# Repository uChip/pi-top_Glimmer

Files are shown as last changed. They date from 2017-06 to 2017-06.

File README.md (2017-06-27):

pi-top_Glimmer  
==============

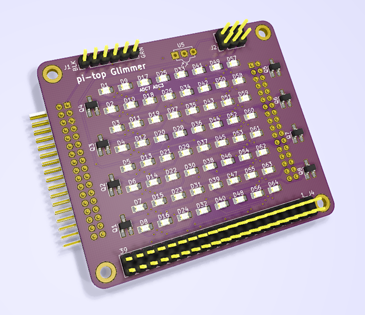
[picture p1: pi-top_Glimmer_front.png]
Accessory board for pi-top laptop or pi-topCEED
  

NOTE: This project is a work in progress and is subject to change.  See the Status section for recent changes.  

This repository contains the design files and write-up for pi-top_Glimmer.  

Note: I have no affiliation with pi-top other than being a customer.  

The pi-top Glimmer is an accessory board for the [pi-topCEED](https://pi-top.com/product/ceed).  It also fits the pi-top laptop.  The board reconstitutes the Raspberry Pi GPIO connector. Unlike the [pi-topPROTO](https://pi-top.com/buy/addon) the Glimmer places the connector optimally for connecting the ["T-Cobbler Plus - GPIO Breakout"](https://www.adafruit.com/product/2028) or the ["Pi Wedge"](https://www.sparkfun.com/products/13717).  

<picture>

The board includes support for an IR Receiver (TSOP38238 or similar) for IR remote control of the pi-top.  An on board ATmega328p (programmable Arduino style) monitors the Raw, 5V and 3.3V voltage levels of the pi-top power supply to help detect if the supply is overloaded.  

The pi-top Glimmer passes the accessory buss through to the other end of the board so that the pi-topSPEAKER or other accessories can be plugged in.  An effort has been made to use a minimum of Raspberry Pi GPIO resources so that as many HATs as possible will still work.  The pi-top HUB board commits GPIO's 7, 9,10 & 11 as the SPI buss with HUB board select on GPIO 7 (CE1_N).  To this the pi-top Glimmer adds the use of GPIOs 2 & 3 as the I2C buss (sharable with other boards) and resides at I2C address 110.  The IR Receiver is optionally connected via solder jumper to GPIO 24 (pin 18).  

Finally, the board includes an 8x8 LED (single color, on/off) array that is refreshed from the Arduino and commanded from the pi-top's Raspberry Pi.  

The software folder contains a "sketch" that is source code for the Arduino which can be changed and updated from the pi-top.  

The board is built using a combination of through-hole and (larger scale) surface mount technologies and is reasonably easy to hand assemble. I created this board for a number of reasons; to more easily enable prototyping on the pi-top, to learn more about the pi-top's accessory buss, to experiment with I2C on both RPi and Arduino, to teach myself KiCad, and to enable future projects I have in mind.  

I did it as a one off, but it seems to have some utility for classroom scenarios.  If there is interest I would be willing to make a manufacturing run of the pi-top Glimmer as a product.  

## Order PCBs  

You can order this PCB directly from OSH Park.  Click on the following link.  
  * pi-top Glimmer - https://oshpark.com/shared_projects/x6jgBiCp  

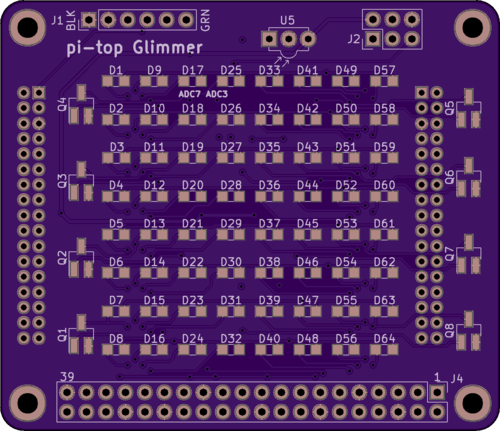
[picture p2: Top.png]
PCB Top
  

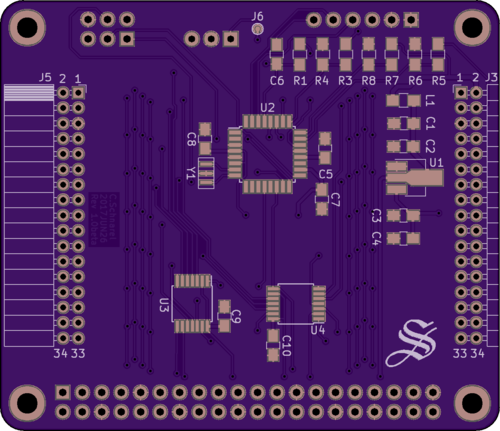
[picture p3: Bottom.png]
PCB Bottom
  

See the Bill of Materials (BOM) file in the repo Hardware folder for a parts list.  

## Status  
  * PCB (rev 1.0beta) has been checked against components and specs and is currently out for fab.  

## File Formats  

Hardware design files are in "KiCad EDA" .kicad_pcb and .sch formats (KiCAD version: (2017-05-14 revision 14bb238b3)).  A free version of the software can be downloaded from kicad-pcb.org.  

The example code is in Arduino .ino format (text).  A free version of the Arduino software can be downloaded from www.arduino.cc.  

## Distribution License  

License:  
<br /><span xmlns:dct="http://purl.org/dc/terms/" property="dct:title">pi-top Glimmer</span> by <a xmlns:cc="http://creativecommons.org/ns#" href="https://github.com/uChip/pi-top_Glimmer" property="cc:attributionName" rel="cc:attributionURL">C.Schnarel</a> is licensed under a <a rel="license" href="http://creativecommons.org/licenses/by-sa/4.0/">Creative Commons Attribution-ShareAlike 4.0 International License</a>.

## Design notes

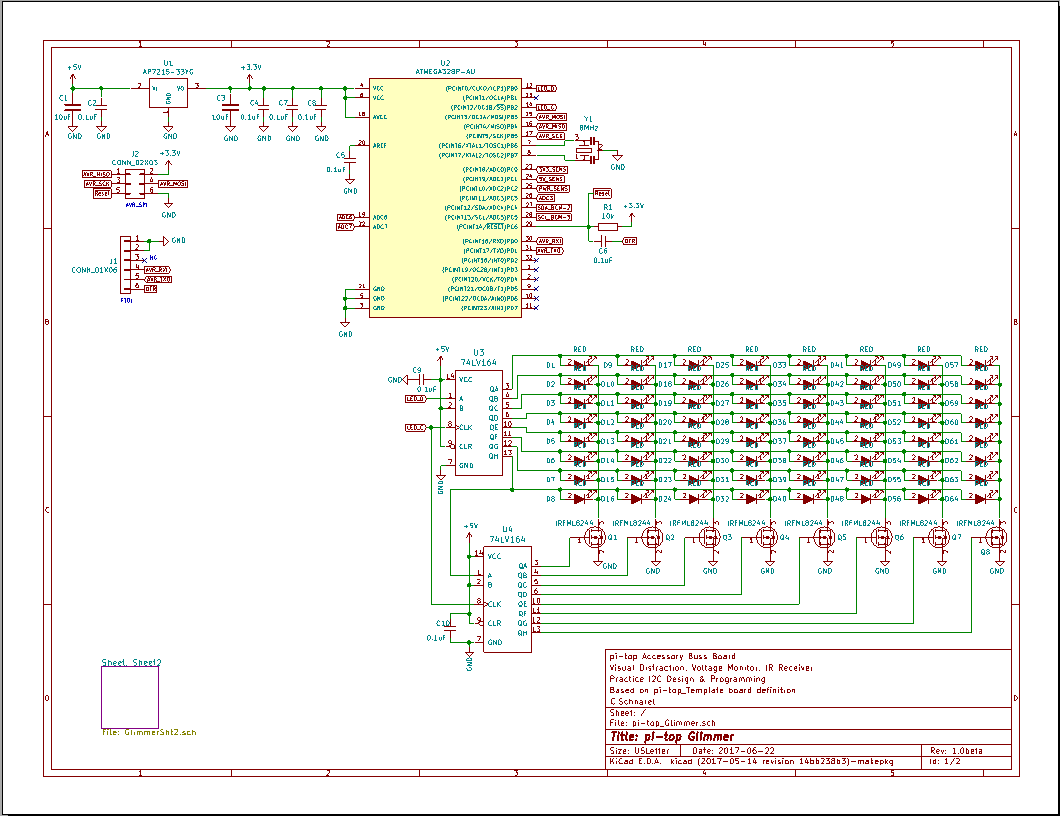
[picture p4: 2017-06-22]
schem1.PNG

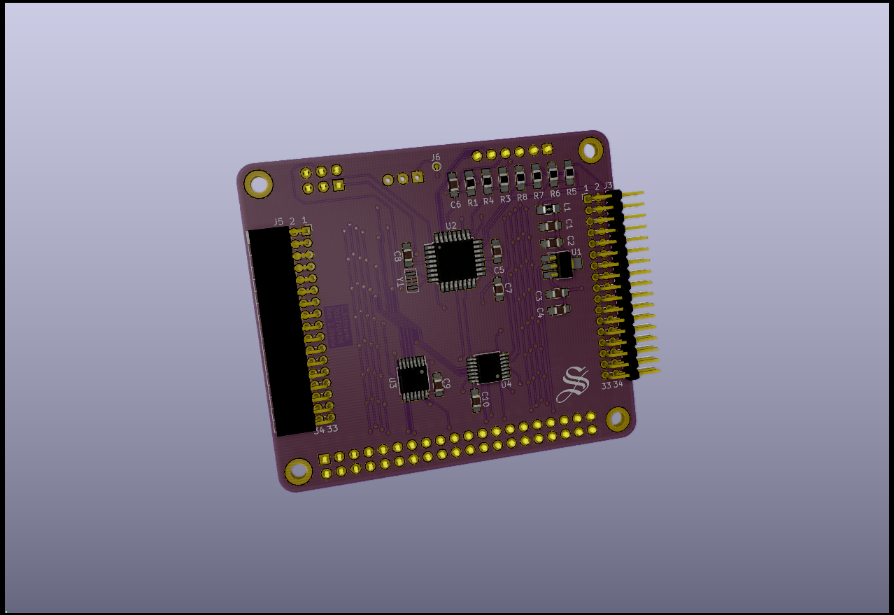
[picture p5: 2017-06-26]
pi-top_Glimmer_back.png

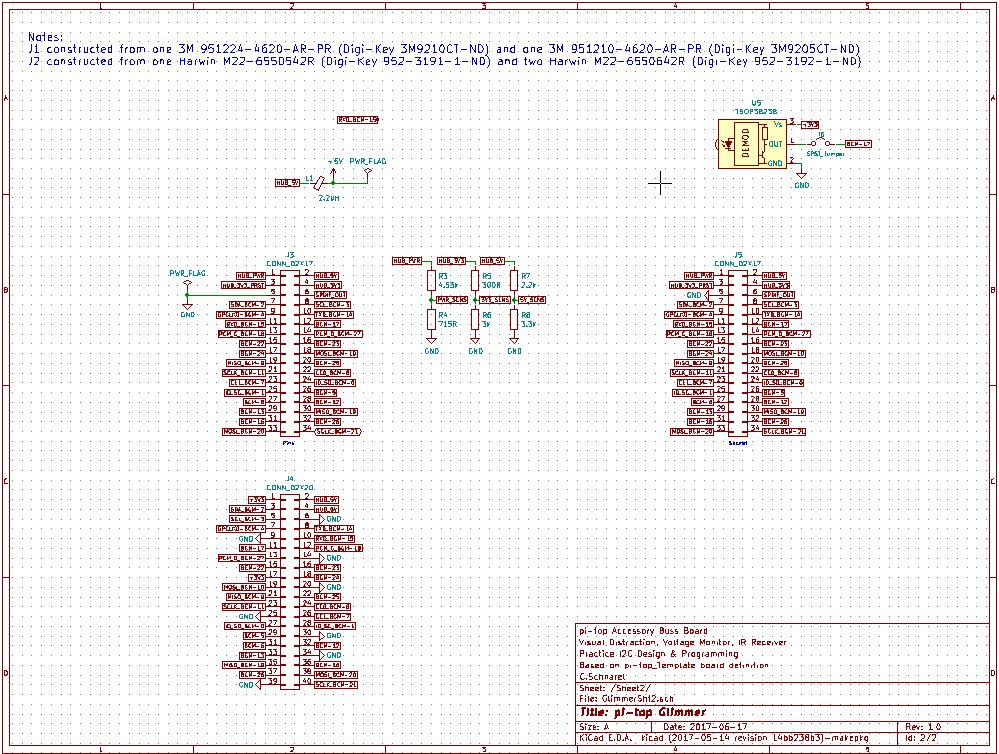
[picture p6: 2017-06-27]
schem2.PNG

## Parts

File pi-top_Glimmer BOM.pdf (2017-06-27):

## pi-top_Glimmer BOM

Id Designator | Package | Quantity Designation | Supplier and ref | $ | $ Tot
1 J5 | Socket_Strip_Angled_2x17_Pitch2.00mm | 1 | CONN_02X17 | Digi-Key #SAM11861-ND plus Digi-Key #SAM9981-ND | $ | 5.79 $ | 5.79
2 J3 | Pin_Header_Angled_2x17_Pitch2.00mm | 1 | CONN_02X17 | Digi-Key #3M9171-34-ND | $ | 4.03 $ | 4.03
3 J4 | Pin_Header_Straight_2x20_Pitch2.54mm | 1 | CONN_02X20 | Digi-Key #S2011EC-20-ND | $ | 0.93 $ | 0.93
4 U3,U4 | TSSOP-14_4.4x5mm_Pitch0.65mm | 2 | 74LV164 | Digi-Key #296-3788-1-ND | $ | 0.42 $ | 0.84
5 Q1,Q2,Q3,Q4,Q5,Q6,Q7,Q8 | SOT-23_Handsoldering | 8 | IRFML8244 | Digi-Key #IRFML8244TRPBFCT-ND | $ | 0.38 $ | 3.04

6

D18,D1,D2,D3,D4,D5,D6,D7,D8,D9,D10,D11,D12,D13,D14
,D15,D16,D17,D19,D20,D21,D22,D23,D24,D25,D26,D27,D
28,D29,D30,D31,D32,D33,D34,D35,D36,D37,D38,D39,D4
0,D41,D42,D43,D44,D45,D46,D47,D48,D49,D50,D51,D52,
D53,D54,D55,D56,D57,D58,D59,D60,D61,D62,D63,D64 | LED_0805 | 64 | RED | Digi-Key #475-1278-1-ND or similar | $ | 0.10 $ | 6.39
7 C1,C3 | C_0805_HandSoldering | 2 | 10uF | Digi-Key #C2012X5R1V106K085AC | $ | 0.73 $ | 1.46
8 C2,C4,C5,C6,C7,C8,C9,C10 | C_0805_HandSoldering | 8 | 0.1uF | Digi-Key #CC0805ZRY5V9BB104 | $ | 0.04 $ | 0.30
9 J1 | Pin_Header_Straight_1x06_Pitch2.54mm | 1 | CONN_01X06 | Digi-Key #609-3272-ND | $ | 0.34 $ | 0.34
10 L1 | L_0805_HandSoldering | 1 | FERRITE BEAD 2.5 KOHM 0805 1LN | Digi-Key #1276-6377-1-ND | $ | 0.10 $ | 0.10
11 R1 | R_0805_HandSoldering | 1 | 10k 1/8W 5% | Digi-Key #P10KACT-ND | $ | 0.10 $ | 0.10
12 R3 | R_0805_HandSoldering | 1 | 4.53k 1/8W 1% | Digi-Key #311-4.53KCRCT-ND | $ | 0.10 $ | 0.10
13 R4 | R_0805_HandSoldering | 1 | 715R 1/8W 1% | Digi-Key #311-715CRCT-ND | $ | 0.10 $ | 0.10
14 R5 | R_0805_HandSoldering | 1 | 300R 1/8W 1% | Digi-Key #311-300CRCT-ND | $ | 0.10 $ | 0.10
15 R6 | R_0805_HandSoldering | 1 | 3k 1/8W 1% | Digi-Key #311-3.00KCRCT-ND | $ | 0.10 $ | 0.10
16 R7 | R_0805_HandSoldering | 1 | 2.2k 1/8W 1% | Digi-Key #311-2.20KCRCT-ND | $ | 0.10 $ | 0.10
17 R8 | R_0805_HandSoldering | 1 | 3.3k 1/8W 1% | Digi-Key #311-3.30KCRCT-ND | $ | 0.10 $ | 0.10
18 U5 | IRReceiver_Vishay_MINICAST-3pin | 1 | TSOP38238 | Digi-Key #751-1227-ND | $ | 1.12 $ | 1.12
19 U2 | TQFP-32_7x7mm_Pitch0.8mm | 1 | ATMEGA328P-AU | Digi-Key #ATMEGA328P-AU-ND | $ | 2.07 $ | 2.07
20 Y1 | Resonator_SMD_muRata_CSTCE_3.2mm_1.3mm 1 | 8MHz | Digi-Key #490-1195-1-ND | $ | 0.48 $ | 0.48
21 U1 | SOT-89-3_Handsoldering | 1 | AP7215-33YG | Digi-Key #AP7215-33YG-13DICT-ND | $ | 0.50 $ | 0.50
$ 28.09

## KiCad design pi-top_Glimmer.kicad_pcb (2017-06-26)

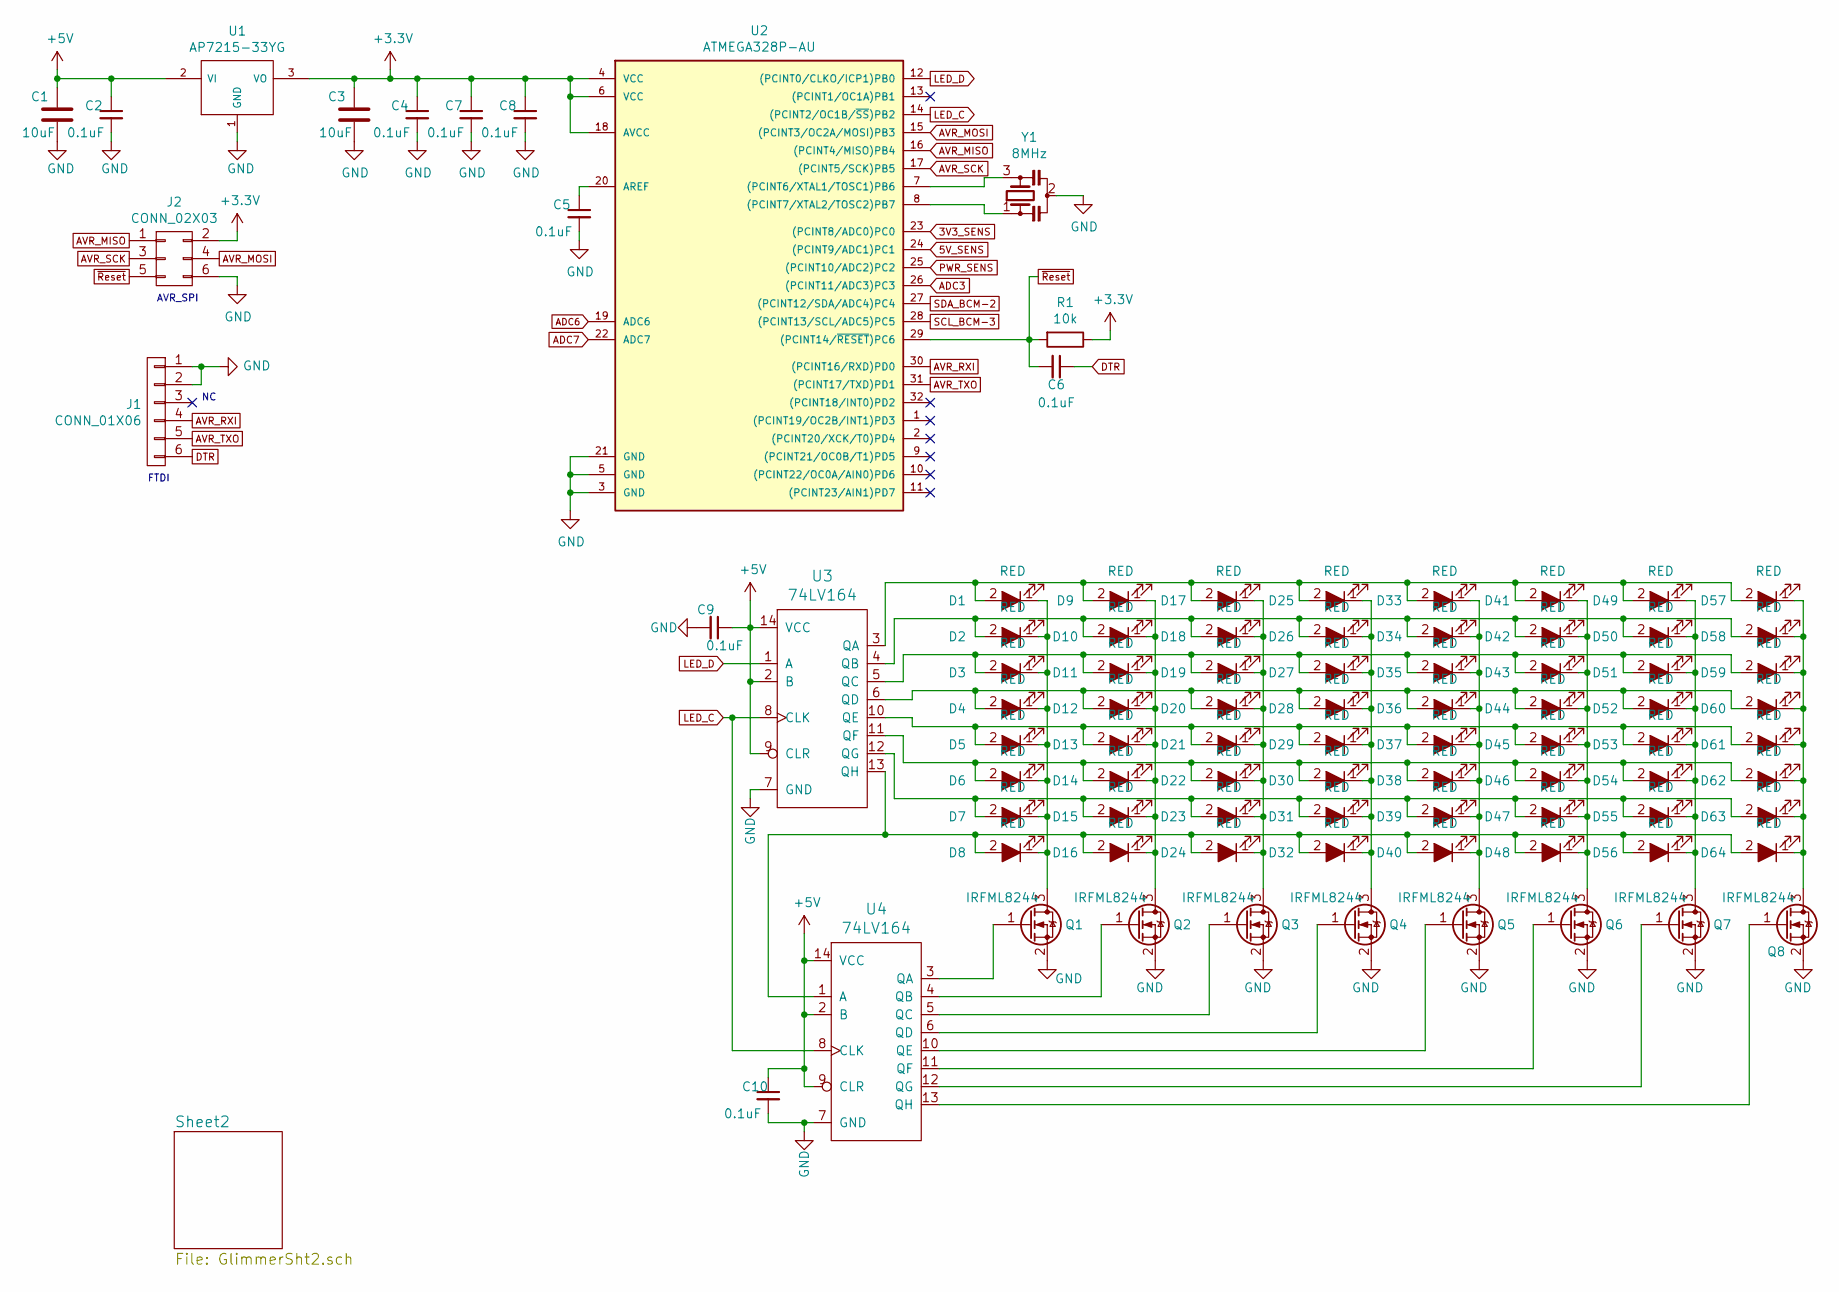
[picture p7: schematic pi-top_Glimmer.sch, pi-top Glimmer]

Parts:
C1, C3: 10uF; C_0805_HandSoldering
C2, C4, C5, C6, C7, C8, C9, C10: 0.1uF; C_0805_HandSoldering
D1, D2, D3, D4, D5, D6, D7, D8, D9, D10, D11, D12, D13, D14, D15, D16, D17, D18, D19, D20, D21, D22, D23, D24, D25, D26, D27, D28, D29, D30, D31, D32, D33, D34, D35, D36, D37, D38, D39, D40, D41, D42, D43, D44, D45, D46, D47, D48, D49, D50, D51, D52, D53, D54, D55, D56, D57, D58, D59, D60, D61, D62, D63, D64: RED; LED_0805
J1: CONN_01X06; Pin_Header_Straight_1x06_Pitch2.54mm
J2: CONN_02X03; Pin_Header_Straight_2x03_Pitch2.54mm
Q1, Q2, Q3, Q4, Q5, Q6, Q7, Q8: IRFML8244; SOT-23_Handsoldering
R1: 10k; R_0805_HandSoldering
U1: AP7215-33YG; SOT-89-3_Handsoldering
U2: ATMEGA328P-AU; TQFP-32_7x7mm_Pitch0.8mm
U3, U4: 74LV164; TSSOP-14_4.4x5mm_Pitch0.65mm
Y1: 8MHz; Resonator_SMD_muRata_CSTCE_3.2mm_1.3mm

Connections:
3V3_SENS: U2.23 ((PCINT8/ADC0)PC0); also elsewhere on the board
5V_SENS: U2.24 ((PCINT9/ADC1)PC1); also elsewhere on the board
+5V: C1.1, C2.1, C9.1, C10.1, U1.2 (VI), U3.2 (B), U3.9 (CLR), U3.14 (VCC), U4.2 (B), U4.9 (CLR), U4.14 (VCC); also elsewhere on the board
ADC3: U2.26 ((PCINT11/ADC3)PC3)
ADC6: U2.19 (ADC6)
ADC7: U2.22 (ADC7)
AVR_MISO: J2.1, U2.16 ((PCINT4/MISO)PB4)
AVR_MOSI: J2.4, U2.15 ((PCINT3/OC2A/MOSI)PB3)
AVR_RXI: J1.4, U2.30 ((PCINT16/RXD)PD0)
AVR_SCK: J2.3, U2.17 ((PCINT5/SCK)PB5)
AVR_TXO: J1.5, U2.31 ((PCINT17/TXD)PD1)
DTR: C6.1, J1.6
GND: C1.2, C2.2, C3.2, C4.2, C5.2, C7.2, C8.2, C9.2, C10.2, J1.1, J1.2, J2.6, Q1.2 (S), Q2.2 (S), Q3.2 (S), Q4.2 (S), Q5.2 (S), Q6.2 (S), Q7.2 (S), Q8.2 (S), U1.1 (GND), U2.3 (GND), U2.5 (GND), U2.21 (GND), U3.7 (GND), U4.7 (GND), Y1.2; also elsewhere on the board
LED_C: U2.14 ((PCINT2/OC1B/~SS~)PB2), U3.8 (CLK), U4.8 (CLK)
LED_D: U2.12 ((PCINT0/CLKO/ICP1)PB0), U3.1 (A)
unnamed: C5.1, U2.20 (AREF)
unnamed: D1.1 (K), D2.1 (K), D3.1 (K), D4.1 (K), D5.1 (K), D6.1 (K), D7.1 (K), D8.1 (K), Q1.3 (D)
unnamed: D1.2 (A), D9.2 (A), D17.2 (A), D25.2 (A), D33.2 (A), D41.2 (A), D49.2 (A), D57.2 (A), U3.3 (QA)
unnamed: D9.1 (K), D10.1 (K), D11.1 (K), D12.1 (K), D13.1 (K), D14.1 (K), D15.1 (K), D16.1 (K), Q2.3 (D)
unnamed: D2.2 (A), D10.2 (A), D18.2 (A), D26.2 (A), D34.2 (A), D42.2 (A), D50.2 (A), D58.2 (A), U3.4 (QB)
unnamed: D3.2 (A), D11.2 (A), D19.2 (A), D27.2 (A), D35.2 (A), D43.2 (A), D51.2 (A), D59.2 (A), U3.5 (QC)
unnamed: D4.2 (A), D12.2 (A), D20.2 (A), D28.2 (A), D36.2 (A), D44.2 (A), D52.2 (A), D60.2 (A), U3.6 (QD)
unnamed: D5.2 (A), D13.2 (A), D21.2 (A), D29.2 (A), D37.2 (A), D45.2 (A), D53.2 (A), D61.2 (A), U3.10 (QE)
unnamed: D6.2 (A), D14.2 (A), D22.2 (A), D30.2 (A), D38.2 (A), D46.2 (A), D54.2 (A), D62.2 (A), U3.11 (QF)
unnamed: D7.2 (A), D15.2 (A), D23.2 (A), D31.2 (A), D39.2 (A), D47.2 (A), D55.2 (A), D63.2 (A), U3.12 (QG)
unnamed: D8.2 (A), D16.2 (A), D24.2 (A), D32.2 (A), D40.2 (A), D48.2 (A), D56.2 (A), D64.2 (A), U3.13 (QH), U4.1 (A)
unnamed: D17.1 (K), D18.1 (K), D19.1 (K), D20.1 (K), D21.1 (K), D22.1 (K), D23.1 (K), D24.1 (K), Q3.3 (D)
unnamed: D25.1 (K), D26.1 (K), D27.1 (K), D28.1 (K), D29.1 (K), D30.1 (K), D31.1 (K), D32.1 (K), Q4.3 (D)
unnamed: D33.1 (K), D34.1 (K), D35.1 (K), D36.1 (K), D37.1 (K), D38.1 (K), D39.1 (K), D40.1 (K), Q5.3 (D)
unnamed: D41.1 (K), D42.1 (K), D43.1 (K), D44.1 (K), D45.1 (K), D46.1 (K), D47.1 (K), D48.1 (K), Q6.3 (D)
unnamed: D49.1 (K), D50.1 (K), D51.1 (K), D52.1 (K), D53.1 (K), D54.1 (K), D55.1 (K), D56.1 (K), Q7.3 (D)
unnamed: D57.1 (K), D58.1 (K), D59.1 (K), D60.1 (K), D61.1 (K), D62.1 (K), D63.1 (K), D64.1 (K), Q8.3 (D)
unnamed: Q1.1 (G), U4.3 (QA)
unnamed: Q2.1 (G), U4.4 (QB)
unnamed: Q3.1 (G), U4.5 (QC)
unnamed: Q4.1 (G), U4.6 (QD)
unnamed: Q5.1 (G), U4.10 (QE)
unnamed: Q6.1 (G), U4.11 (QF)
unnamed: Q7.1 (G), U4.12 (QG)
unnamed: Q8.1 (G), U4.13 (QH)
unnamed: U2.7 ((PCINT6/XTAL1/TOSC1)PB6), Y1.3
unnamed: U2.8 ((PCINT7/XTAL2/TOSC2)PB7), Y1.1
PWR_SENS: U2.25 ((PCINT10/ADC2)PC2); also elsewhere on the board
SCL_BCM-3: U2.28 ((PCINT13/SCL/ADC5)PC5); also elsewhere on the board
SDA_BCM-2: U2.27 ((PCINT12/SDA/ADC4)PC4); also elsewhere on the board
~Reset: C6.2, J2.5, R1.2, U2.29 ((PCINT14/~RESET~)PC6)

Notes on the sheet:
FTDI
AVR_SPI

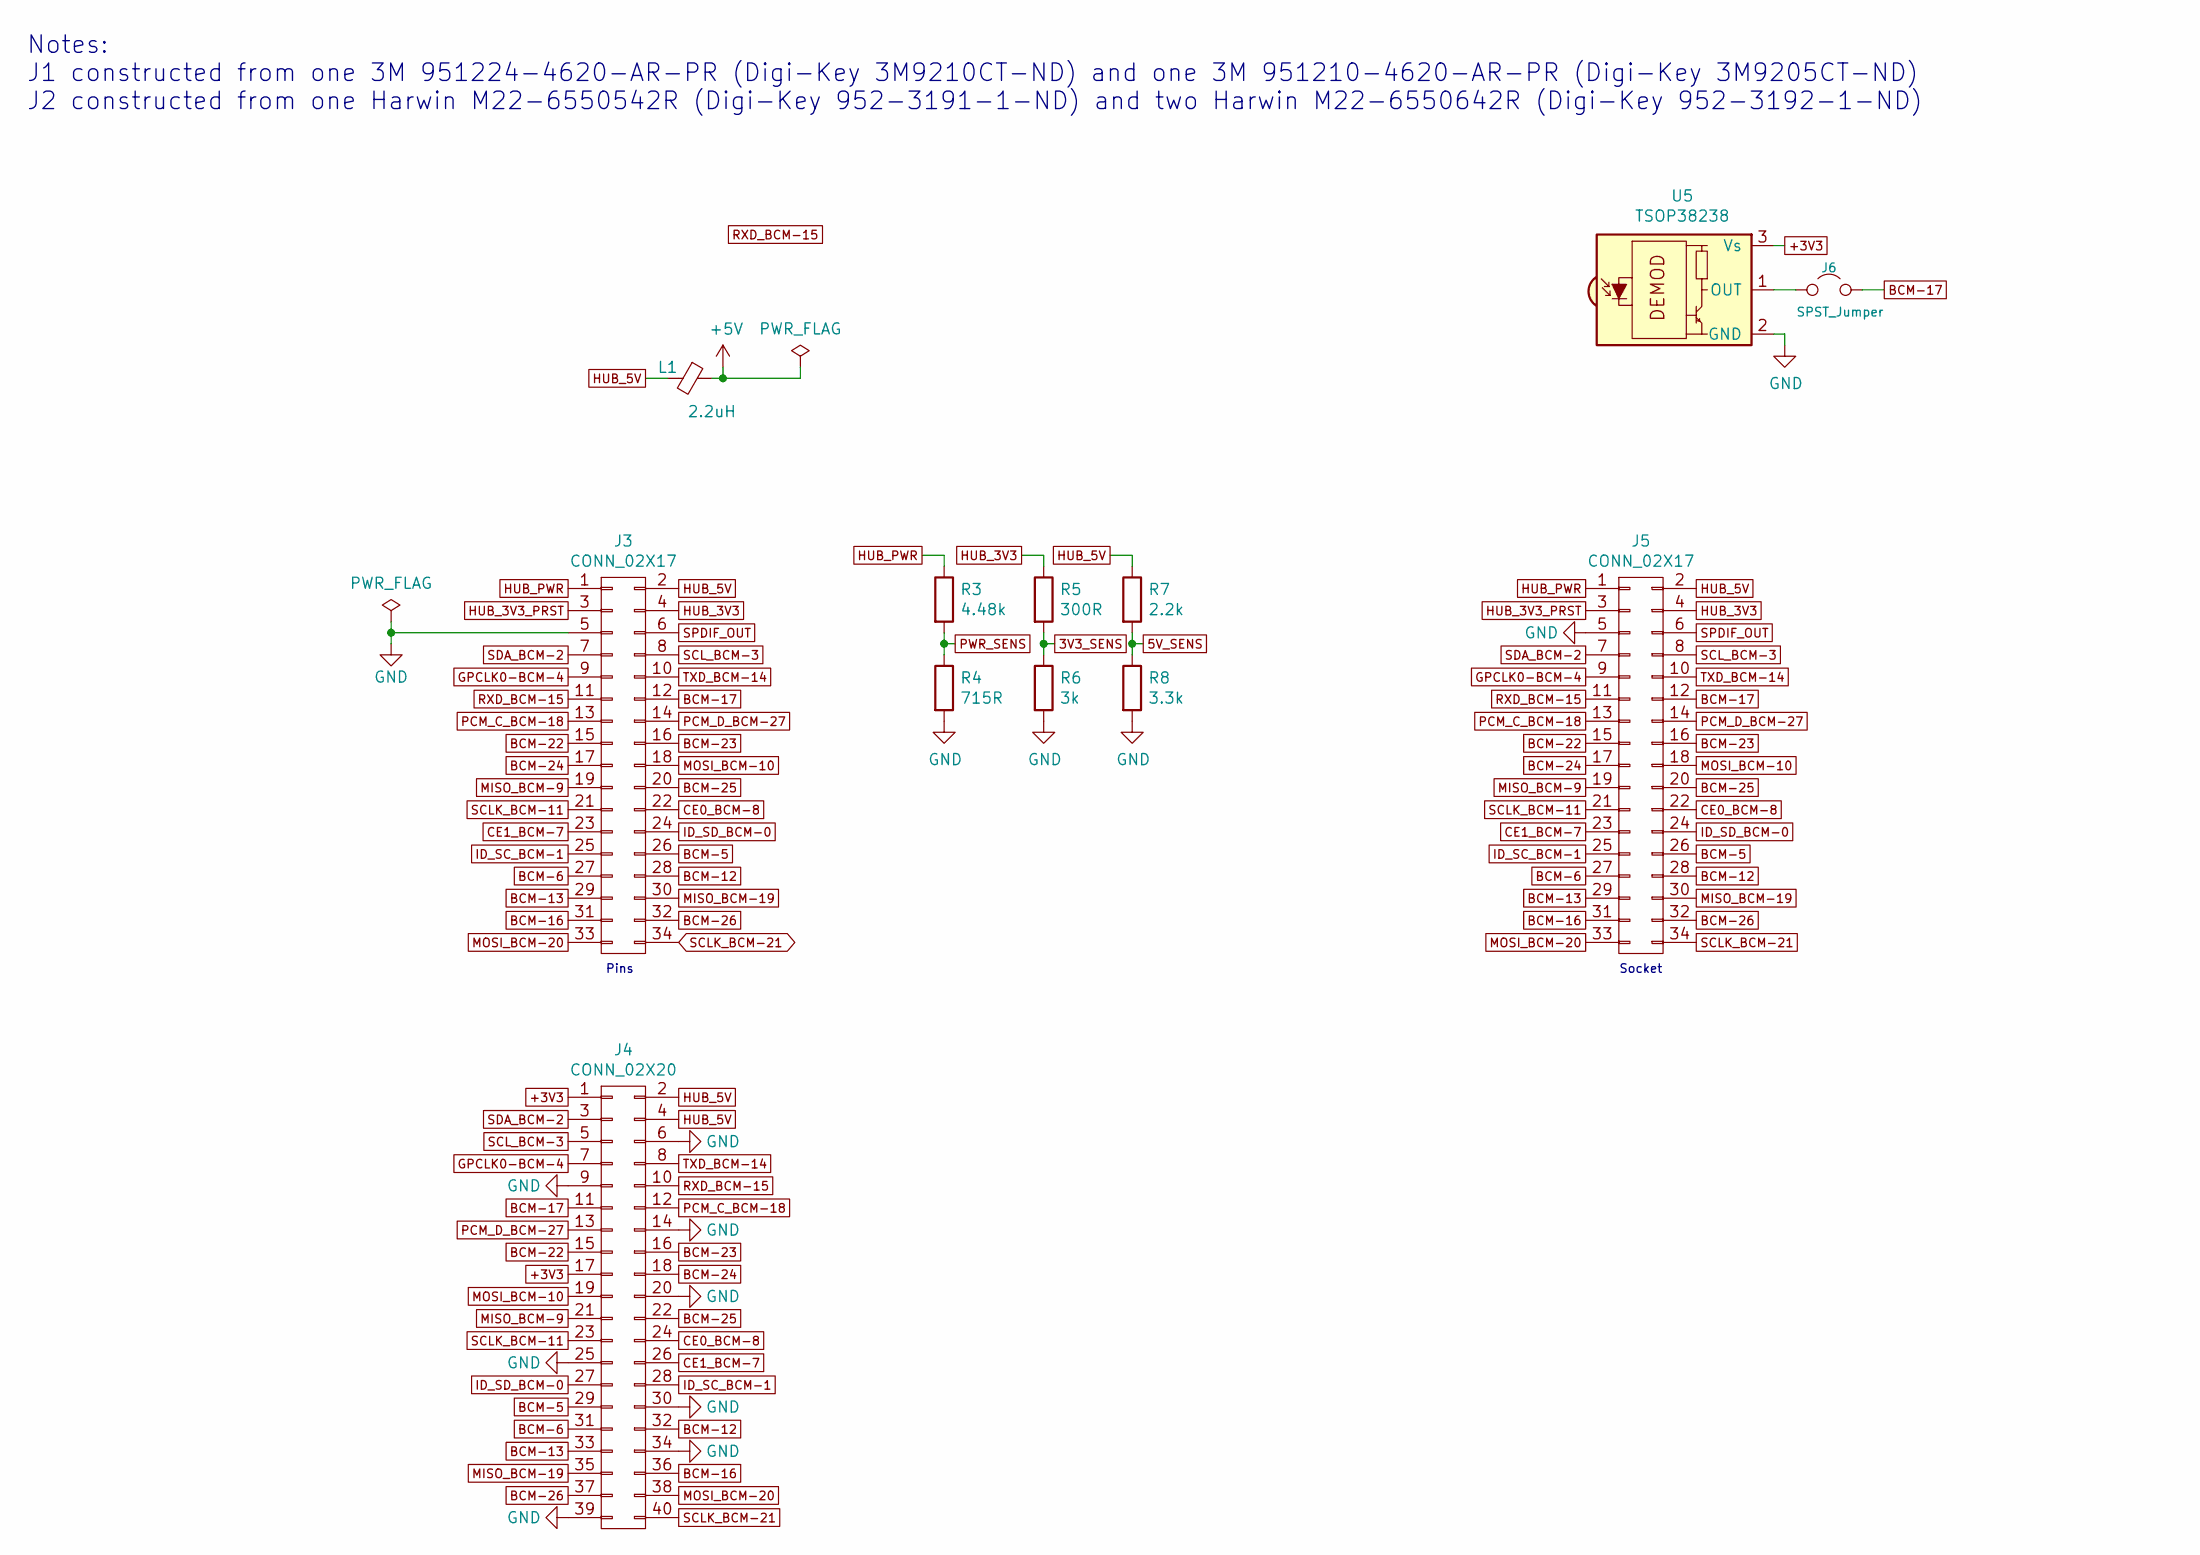
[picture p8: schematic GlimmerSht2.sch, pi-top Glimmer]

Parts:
J3: CONN_02X17; 3M_951217-4620-XX
J4: CONN_02X20; Pin_Header_Straight_2x20_Pitch2.54mm
J5: CONN_02X17; Harwin_M22-6553442R
J6: SPST_Jumper
L1: 2.2uH; L_0805_HandSoldering
R3: 4.48k; R_0805_HandSoldering
R4: 715R; R_0805_HandSoldering
R5: 300R; R_0805_HandSoldering
R6: 3k; R_0805_HandSoldering
R7: 2.2k; R_0805_HandSoldering
R8: 3.3k; R_0805_HandSoldering
U5: TSOP38238; IRReceiver_Vishay_MINICAST-3pin

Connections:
3V3_SENS: R5.2, R6.1; also elsewhere on the board
5V_SENS: R7.2, R8.1; also elsewhere on the board
+5V: L1.1; also elsewhere on the board
BCM-5: J3.26, J4.29, J5.26
BCM-6: J3.27, J4.31, J5.27
BCM-12: J3.28, J4.32, J5.28
BCM-13: J3.29, J4.33, J5.29
BCM-16: J3.31, J4.36, J5.31
BCM-17: J3.12, J4.11, J5.12, J6.2 (B)
BCM-22: J3.15, J4.15, J5.15
BCM-23: J3.16, J4.16, J5.16
BCM-24: J3.17, J4.18, J5.17
BCM-25: J3.20, J4.22, J5.20
BCM-26: J3.32, J4.37, J5.32
CE0_BCM-8: J3.22, J4.24, J5.22
CE1_BCM-7: J3.23, J4.26, J5.23
GND: J3.5, J4.6, J4.9, J4.14, J4.20, J4.25, J4.30, J4.34, J4.39, J5.5, R4.2, R6.2, R8.2, U5.2 (GND); also elsewhere on the board
GPCLK0-BCM-4: J3.9, J4.7, J5.9
HUB_3V3: J3.4, J5.4, R5.1
HUB_3V3_PRST: J3.3, J5.3
HUB_5V: J3.2, J4.2, J4.4, J5.2, L1.2, R7.1
HUB_PWR: J3.1, J5.1, R3.1
ID_SC_BCM-1: J3.25, J4.28, J5.25
ID_SD_BCM-0: J3.24, J4.27, J5.24
MISO_BCM-9: J3.19, J4.21, J5.19
MISO_BCM-19: J3.30, J4.35, J5.30
MOSI_BCM-10: J3.18, J4.19, J5.18
MOSI_BCM-20: J3.33, J4.38, J5.33
unnamed: J6.1 (A), U5.1 (OUT)
PCM_C_BCM-18: J3.13, J4.12, J5.13
PCM_D_BCM-27: J3.14, J4.13, J5.14
PWR_SENS: R3.2, R4.1; also elsewhere on the board
RXD_BCM-15: J3.11, J4.10, J5.11
SCLK_BCM-11: J3.21, J4.23, J5.21
SCLK_BCM-21: J3.34, J4.40, J5.34
SCL_BCM-3: J3.8, J4.5, J5.8; also elsewhere on the board
SDA_BCM-2: J3.7, J4.3, J5.7; also elsewhere on the board
SPDIF_OUT: J3.6, J5.6
TXD_BCM-14: J3.10, J4.8, J5.10

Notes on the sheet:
Pins
Socket
Notes: J1 constructed from one 3M 951224-4620-AR-PR (Digi-Key 3M9210CT-ND) and one 3M 951210-4620-AR-PR (Digi-Key 3M9205CT-ND) J2 constructed from one Harwin M22-6550542R (Digi-Key 952-3191-1-ND) and two Harwin M22-6550642R (Digi-Key 952-3192-1-ND)

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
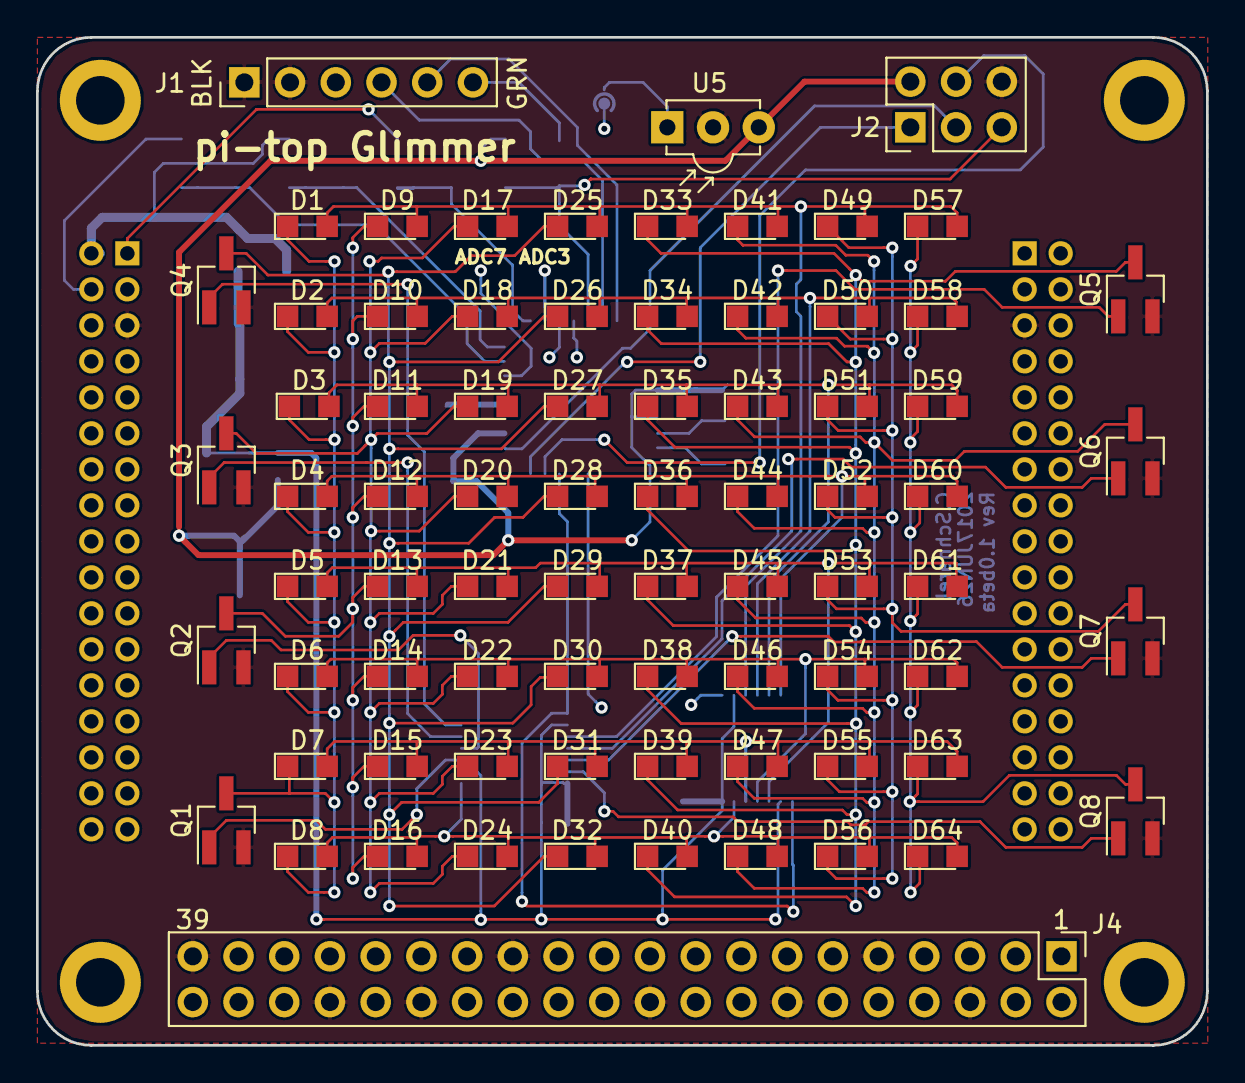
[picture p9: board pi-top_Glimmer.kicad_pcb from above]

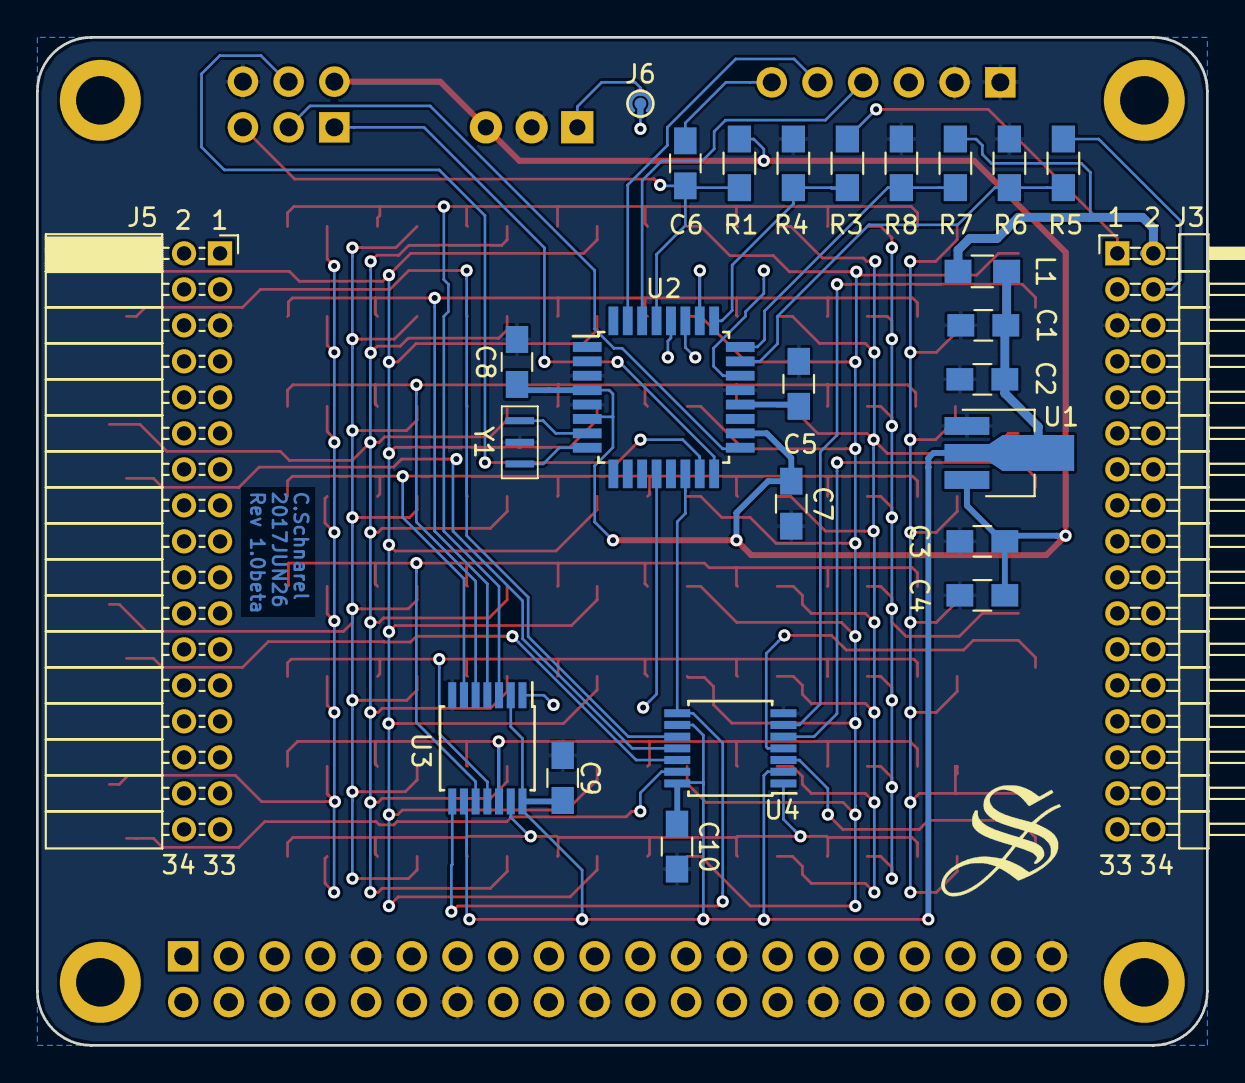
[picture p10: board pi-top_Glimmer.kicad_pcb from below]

Board: 4 copper layers, 65.0 x 56.0 mm, 102 parts (26 on the bottom side), 76 nets.

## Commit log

2017-06-22 Creating repository
    [GlimmerSht2.sch, pi-top_Glimmer.kicad_pcb, pi-top_Glimmer.sch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]
2017-06-26 Added solder jumper to IR Rcvr; README edits
    [GlimmerSht2.sch, pi-top_Glimmer.kicad_pcb, pi-top_Glimmer.sch]
2017-06-27 Updated PCB renders; README edits
    Added OSH Park shared project permalink
2017-06-27 Adding BOM
    Parts availability caused change to schem2
    [GlimmerSht2.sch, pi-top_Glimmer BOM.xlsx]
2017-06-27 removed temp file
    [pi-top_GlimmerL.kicad_pcb]
